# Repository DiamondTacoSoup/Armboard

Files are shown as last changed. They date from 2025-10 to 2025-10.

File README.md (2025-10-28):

# WHY ArmBoard?
We have all been there (well I have at least). Your friend says something funny, goofy, or pretty much anything and you think to yourself "I wish I could play a sound effect IRL, that would inject a lot of humour into this situation". Whether that be a generic laughing track or some obscure in joke, I believe on-demand audio add depth to any situation.

The issue we face as a society is that despite having phones which can play any sound imaginable the process of play a sound on a phone is clunky and time consuming. You must pull out and unlock your phone, look up the audio, find the correct version, wait for it to load, and then finally you can play a sound. The issue here being that this possess is time consuming, and many of these jokes/situations are time dependant.

It is clear from this that the need for a more convenient method of playing audio is required. And what could be more convenient than big buttons strapped to your wrist. It is always within arms reach, literally!  That is why I decided to create the ArmBoard, as an audio solution for the masses.

# How does it work?
The main system is comprised of 3 main parts, the esp32, the screen buttons, and the Dfplayer mini. Each of these systems have multiple sub components and functions. 

The esp32 is the brains of the operations, the TinyPico I have opted to use is optimal due to its small form factor and high number of GPIO pins. Allowing for the control of many differant components within a miniture package.

The screen buttons are made up of two distinct components, the screen and the buttons. The screens I have used are 0.66in two tone OLED displays. These are cheap, small, and bright. I have chosen to use the breakout board version of the screens as it simplifys soldering an circutry. The buttons I have chosen are the cherry MX ultra low profile. Unfortunatly these switches can only be bought from two suppliers, one in china and one in germany, they are also quite pricey. Depsite this I have still used them because of their incredibly thin form factor. 
The TinyPico does not have enough GPIO pins for each switch to have its own, as such I have arrange the switches into 4 sets of 3 switches. Each switch has a differant value resistor attatched to it (1000, 4700, and 10,000 ohm). As such, when pressed each switch in each set will produce a differant voltage. This reduces the number of Inputs needed on the TinyPico from 12 GPIO pins to just 4 analogue inputs. 
The TinyPico communicates to the Displays over I2C. Each display only supports 2 I2C addresses, as such I have had to use an I2C multiplexer to create 6 discrete I2C lines. For this task I have used the TCA9548APWR, a common I2C multiplexer. This takes one I2C line and 3 GPIO pins as input. The I2C lines carry the signal and the GPIO lines select the output using binary where each GPIO represents one digit.

Finally, the sound system consists of a DFplayer mini and a small 0.5w speaker. The DFplayer is a premade mp3 player board, the TinyPico uses a UART connection to select from mp3 files stored on an sd card within the DFplayer. The DFplayer, which incorporates a DAC, amp, and SD card, then outputs that sound signal to the speaker.

# Images
PCB:



Schematic:



3d Models:




# BOM (All prices are AUD)
| PCB designation | Name | Quantity | Product number / Website | Unit price | Total price |
|---|---|---|---|---|---|
| XA1 | TinyPico | 1 | 392-TP-N-01 | $30.40 | $30.40 |
| R10,R4,R1,R7 | 3216 Metric 1000Ohm | 4 | 704-MFBW1V3216-152-R | $0.10 | $0.38 |
| R6,R12,R15,R9,R3,R13,R16,R14 | 3216 Metric 10000Ohm | 8 | 652-CRT1206BY1002ELF | $0.21 | $1.68 |
| R8,R5,R2,R11 | 3216 Metric 4700Ohm | 4 | 603-RT1206BRD074K7L | $0.19 | $0.74 |
| U1 | TCA9548APWR | 1 | 595-TCA9548APWR | $3.65 | $3.65 |
| U2 | Dfplayer mini | 1 | [AliExpress Link](https://www.aliexpress.com/item/1005001417104130.html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!!!) | $3.06 | $3.06 |
| SW12,SW3,SW1,SW9,SW2,SW8,SW5,SW10,SW6,SW7,SW11,SW4 | Cherry ULP SMD switches | 12 | [Reichelt Link](https://www.reichelt.de/de/en/shop/product/cherry_mx_ultra_low_profile_rgb_-_pushbutton_module-335040) | $2.66 | $31.92 |
| D8,D4,D2,D12,D6,D10,D7,D3,D5,D9,D11,D1 | Display_0.66in | 12 | [BuyDisplay Link](https://www.buydisplay.com/i2c-white-0-66-inch-oled-display-module-64x48-arduino-raspberry-pi) | $4.92 | $59.04 |
| — | Battery | 1 | [AliExpress Link](https://www.aliexpress.com/p/tesla-landing/index.html?productId=4001029210544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) | $12.39 | $12.39 |
| LS1 | Buzzer_12mm (6.5mm hole) | 1 | MT-TH12-0126-RK | $2.30 | $2.30 |
| ~ | **Overall cost (excluding shipping)** | ~ | ~ | ~ | **$133.18**  |

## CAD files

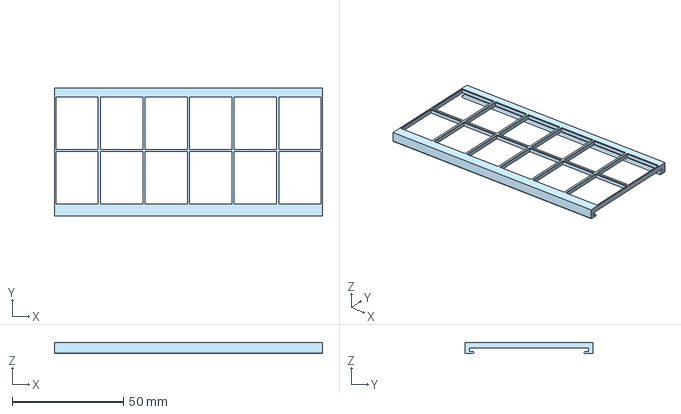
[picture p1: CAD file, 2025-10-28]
3D Models/ArmBoard Faceplate.step
120.2 x 57.4 x 5.10 mm

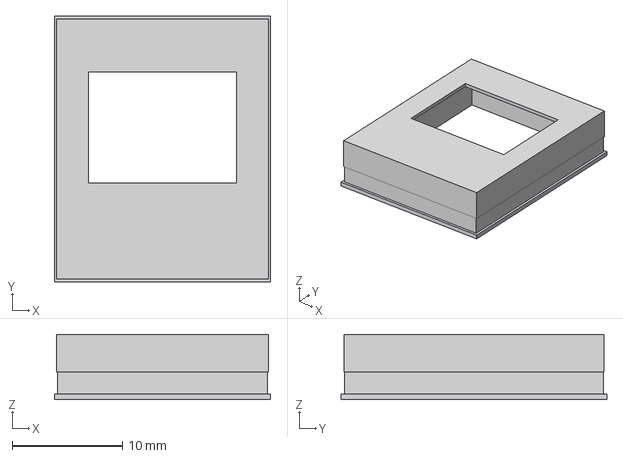
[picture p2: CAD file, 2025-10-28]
3D Models/ArmBoard Button Screen Housing.step
19.6 x 24.1 x 5.90 mm

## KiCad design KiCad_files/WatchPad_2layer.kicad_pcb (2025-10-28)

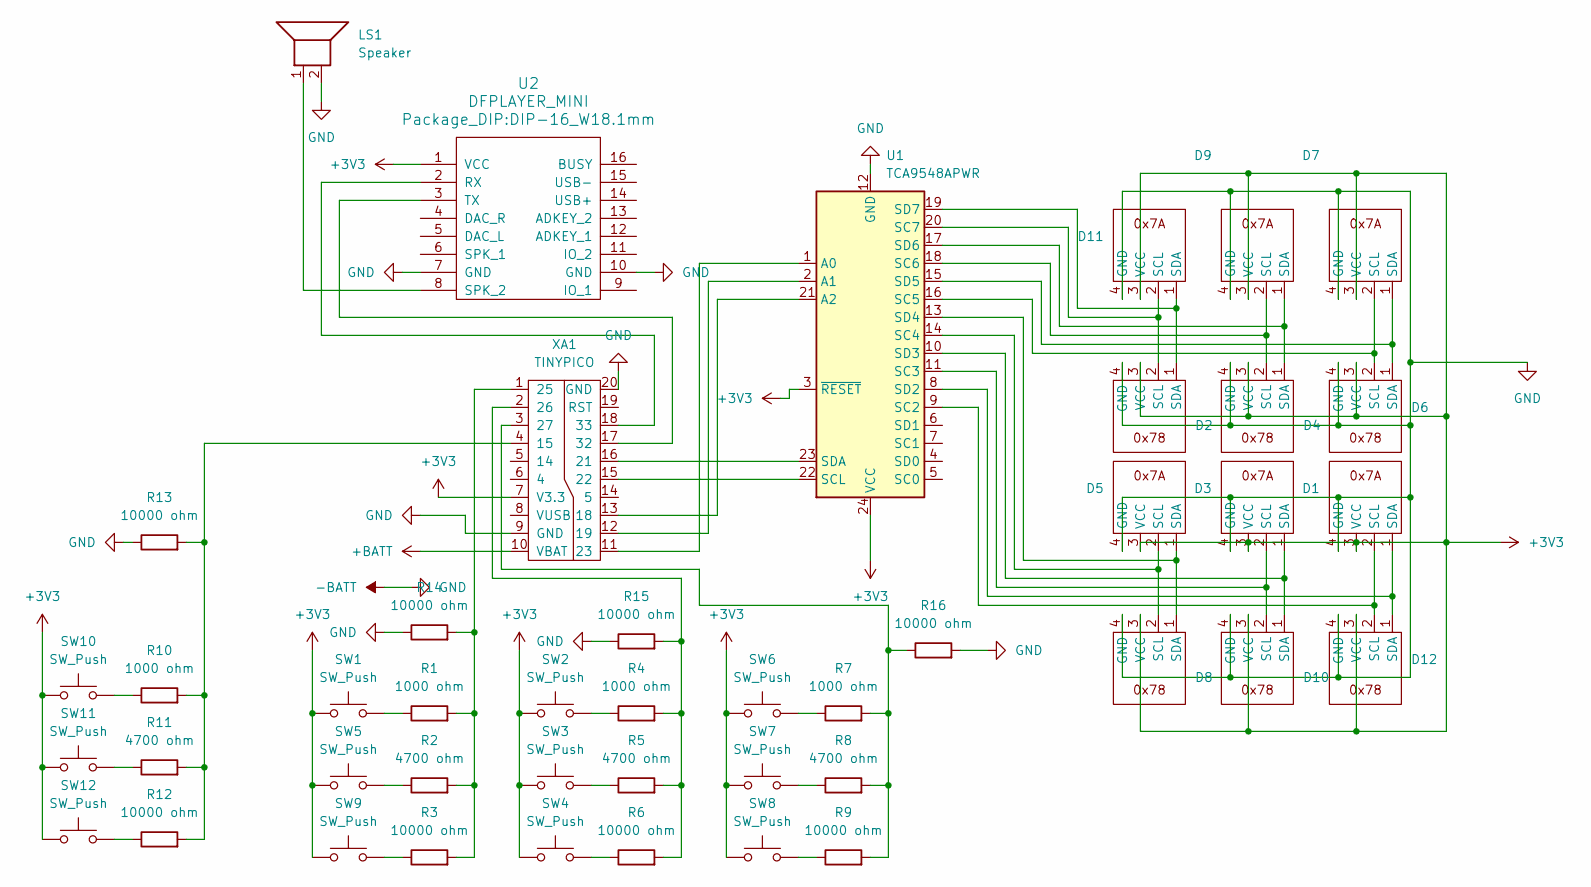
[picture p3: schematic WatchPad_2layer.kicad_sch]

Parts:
D1, D3, D5, D7, D9, D11: Display_0.66in_0x7A
D2, D4, D6, D8, D10, D12: Display_0.66in_0x78
LS1: Speaker; Buzzer_TDK_PS1240P02BT_D12.2mm_H6.5mm
R1, R4, R7, R10: 1000 ohm; R_1206_3216Metric
R2, R5, R8, R11: 4700 ohm; R_1206_3216Metric
R3, R6, R9, R12, R13, R14, R15, R16: 10000 ohm; R_1206_3216Metric
SW1, SW2, SW3, SW4, SW5, SW6, SW7, SW8, SW9, SW10, SW11, SW12: SW_Push; Cherry ULP SMD
U1: TCA9548APWR; TSSOP-24_4.4x7.8mm_P0.65mm
U2: DFPLAYER_MINI; DIP-16_W18.1mm
XA1: TINYPICO

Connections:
+3V3: D1.3 (VCC), D2.3 (VCC), D3.3 (VCC), D4.3 (VCC), D5.3 (VCC), D6.3 (VCC), D7.3 (VCC), D8.3 (VCC), D9.3 (VCC), D10.3 (VCC), D11.3 (VCC), D12.3 (VCC), SW1.1, SW2.1, SW3.1, SW4.1, SW5.1, SW6.1, SW7.1, SW8.1, SW9.1, SW10.1, SW11.1, SW12.1, U1.3 (~RESET), U1.24 (VCC), U2.1 (VCC), XA1.7 (V3.3)
+BATT: XA1.10 (VBAT)
-BATT: D1.4 (GND), D2.4 (GND), D3.4 (GND), D4.4 (GND), D5.4 (GND), D6.4 (GND), D7.4 (GND), D8.4 (GND), D9.4 (GND), D10.4 (GND), D11.4 (GND), D12.4 (GND), LS1.2, R13.1, R14.1, R15.1, R16.2, U1.12 (GND), U2.7 (GND), U2.10 (GND), XA1.9 (GND), XA1.20 (GND)
unnamed: D1.2 (SCL), D12.2 (SCL), U1.9 (SC2)
unnamed: D1.1 (SDA), D12.1 (SDA), U1.8 (SD2)
unnamed: D4.2 (SCL), D9.2 (SCL), U1.18 (SC6)
unnamed: D4.1 (SDA), D9.1 (SDA), U1.17 (SD6)
unnamed: D5.2 (SCL), D8.2 (SCL), U1.14 (SC4)
unnamed: D5.1 (SDA), D8.1 (SDA), U1.13 (SD4)
unnamed: D6.2 (SCL), D7.2 (SCL), U1.16 (SC5)
unnamed: D6.1 (SDA), D7.1 (SDA), U1.15 (SD5)
unnamed: D3.2 (SCL), D10.2 (SCL), U1.11 (SC3)
unnamed: D3.1 (SDA), D10.1 (SDA), U1.10 (SD3)
unnamed: D2.2 (SCL), D11.2 (SCL), U1.20 (SC7)
unnamed: D2.1 (SDA), D11.1 (SDA), U1.19 (SD7)
unnamed: R1.1, SW1.2
unnamed: R2.1, SW5.2
unnamed: R3.1, SW9.2
unnamed: R4.1, SW2.2
unnamed: R5.1, SW3.2
unnamed: R6.1, SW4.2
unnamed: R7.1, SW6.2
unnamed: R8.1, SW7.2
unnamed: R9.1, SW8.2
unnamed: R10.1, SW10.2
unnamed: R11.1, SW11.2
unnamed: R12.1, SW12.2
unnamed: U1.1 (A0), XA1.11 (23)
unnamed: U1.2 (A1), XA1.12 (19)
unnamed: U1.21 (A2), XA1.13 (18)
unnamed: U1.22 (SCL), XA1.15 (22)
unnamed: U1.23 (SDA), XA1.16 (21)
unnamed: U2.2 (RX), XA1.18 (33)
unnamed: LS1.1, U2.8 (SPK_2)
unnamed: U2.3 (TX), XA1.17 (32)
unnamed: R10.2, R11.2, R12.2, R13.2, XA1.4 (15)
unnamed: R1.2, R2.2, R3.2, R14.2, XA1.1 (25)
unnamed: R4.2, R5.2, R6.2, R15.2, XA1.2 (26)
unnamed: R7.2, R8.2, R9.2, R16.1, XA1.3 (27)

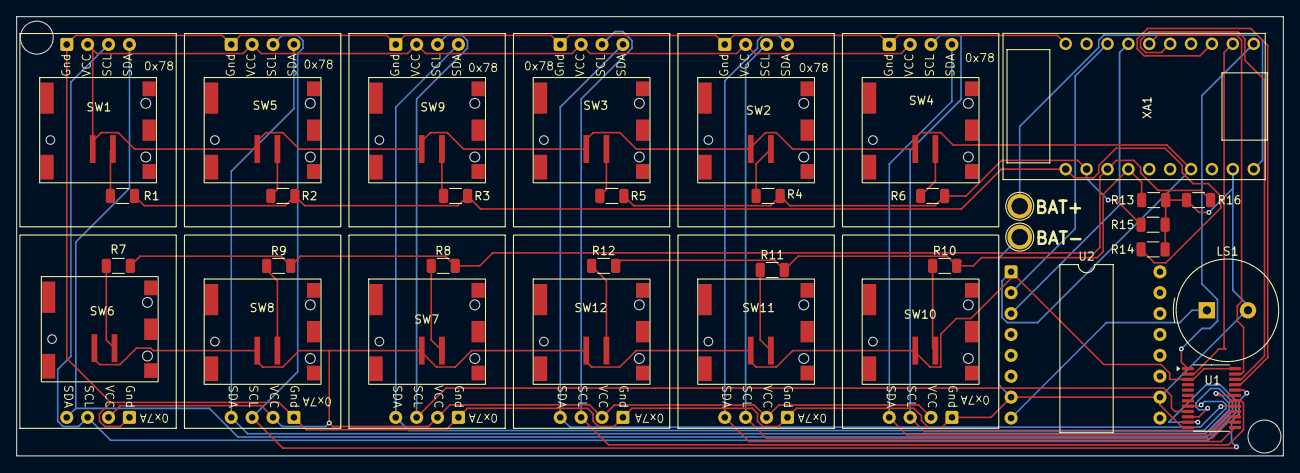
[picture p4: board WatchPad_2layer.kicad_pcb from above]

Board: 2 copper layers, 154.0 x 53.4 mm, 44 parts (0 on the bottom side), 38 nets.

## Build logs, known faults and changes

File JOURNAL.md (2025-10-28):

<!--
  ===================    !!READ THIS NOTICE!!   ====================
  DO NOT edit this file manually. Your changes WILL BE OVERWRITTEN!
  This journal is auto generated and updated by Hack Club Blueprint.
  To edit this file, please edit your journal entries on Blueprint.
  ==================================================================
-->

## 10/4/2025 - Created pcb, cad, and code.  

I didn't realise that I needed to make the journal before the designs so I went ahead and designed my project pre-journal.

PCB:
This project started out as me trying to learn Kicad, I had made some basic circuits but I wanted to try something more challenging and I have had this idea for a while so I started by making a pcb. 
My design uses a TinyPico stm32 microcontroller connected to 12 i2c displays and a dfplayer mini. 
The main challenge was that each display only supported two i2c addresses as such I have been made to use an i2c multiplexer and this was cause for much complexity in my design. Other then that the rest of the circuit is fairly straightforward. Attached are the schematics as well as the footprint:



Cad model:
The cad model at this point is quite basic, by that I mean it is completed but I will not be able to finalise the tolerances until the screens arrive and I am able to take measurements. I am also worried about the wall thickness but I have checked in preform and it should be fine for resin printing, but I may have to make modifications later.



Code:
I have gotten chatgpt to make the code. Not that I have gotten it to do everything, more that I have explained in words how I want the code to work and then have let it do the syntax (bc I hate syntax). If this is an issue I can also rewrite the code myself but that would be a pain.

## 10/28/2025 - Added BOM, Edited PCB, Edited 3D printed faceplate  

Firstly I added a BOM that Includes prices and stores, but excludes shipping costs. 
This mostly contains parts from mouser but also has a few from other suppliers.
The compilation of the BOM took quite a while.

I made some minor edits to the PCB in which I changed the hole spacing for the speaker to a more standard 6.5mm spacing.

I changed the faceplate mounting mechanism from a screw in system to a slide in system as pictured below.




## 10/29/2025 - Cleaned up ReadME, Added STEP files  

This was a minor edit to make the project ready to ship. It required uploading Images to my ReadME and Adding STEP files to my Repo. I also spent a lot of time reading through the shipping requirements to make sure I met them.



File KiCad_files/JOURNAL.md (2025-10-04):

<!--
  ===================    !!READ THIS NOTICE!!   ====================
  DO NOT edit this file manually. Your changes WILL BE OVERWRITTEN!
  This journal is auto generated and updated by Hack Club Blueprint.
  To edit this file, please edit your journal entries on Blueprint.
  ==================================================================
-->

This is my journal of the design and building process of **Armboard**.  
You can view this journal in more detail on **Hack Club Blueprint** [here](https://blueprint.hackclub.com/projects/133).

## 10/4/2025 - Created pcb, cad, and code.  

I didn't realise that I needed to make the journal before the designs so I went ahead and designed my project pre-journal.

PCB:
This project started out as me trying to learn Kicad, I had made some basic circuits but I wanted to try something more challenging and I have had this idea for a while so I started by making a pcb. 
My design uses a bluepill stm32 microcontroller connected to 12 i2c displays and a dfplayer mini. 
The main challenge was that each display only supported two i2c addresses as such I have been made to use an i2c multiplexer and this was cause for much complexity in my design. Other then that the rest of the circuit is fairly straightforward. Attached are the schematics as well as the footprint:



Cad model:
The cad model at this point is quite basic, by that I mean it is completed but I will not be able to finalise the tolerances until the screens arrive and I am able to take measurements. I am also worried about the wall thickness but I have checked in preform and it should be fine for resin printing, but I may have to make modifications later.



Code:
I have gotten chatgpt to make the code. Not that I have gotten it to do everything, more that I have explained in words how I want the code to work and then have let it do the syntax (bc I hate syntax). If this is an issue I can also rewrite the code myself but that would be a pain.

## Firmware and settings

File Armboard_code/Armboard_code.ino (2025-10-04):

#include <Wire.h>
#include <Adafruit_GFX.h>
#include <Adafruit_SSD1306.h>
#include <HardwareSerial.h>
#include <DFRobotDFPlayerMini.h>

// ---------- DISPLAY SETTINGS ----------
#define SCREEN_WIDTH 64
#define SCREEN_HEIGHT 48
#define OLED_RESET    -1
Adafruit_SSD1306 display(SCREEN_WIDTH, SCREEN_HEIGHT, &Wire, OLED_RESET);

#define TCA9548A_ADDR 0x70  // I2C address of multiplexer

// ---------- DFPLAYER SETTINGS ----------
#define DF_RX 16   // TinyPICO RX (to DFPlayer TX)
#define DF_TX 17   // TinyPICO TX (to DFPlayer RX)
HardwareSerial dfSerial(2);  
DFRobotDFPlayerMini dfPlayer;

// ---------- BUTTON SETTINGS ----------
#define COL1_PIN 34   // ADC input for column 1
#define COL2_PIN 35   // ADC input for column 2

int thresholds[6] = {400, 750, 1000, 1300, 1700, 2100}; 
// Adjust after calibration

// ---------- SYMBOL PLACEHOLDER ----------
const uint8_t symbol0[384] PROGMEM = { /* 64x48 bitmap data */ };
const uint8_t symbol1[384] PROGMEM = { /* another symbol */ };
// … up to symbol11
const uint8_t* symbols[12] = {
  symbol0, symbol1, /* … */ 
};

// ---------- HELPERS ----------
void tcaSelect(uint8_t channel) {
  if (channel > 7) return;
  Wire.beginTransmission(TCA9548A_ADDR);
  Wire.write(1 << channel);
  Wire.endTransmission();
}

int readButtonColumn(int analogPin) {
  int val = analogRead(analogPin);
  if (val < thresholds[0]) return 1;
  else if (val < thresholds[1]) return 2;
  else if (val < thresholds[2]) return 3;
  else if (val < thresholds[3]) return 4;
  else if (val < thresholds[4]) return 5;
  else if (val < thresholds[5]) return 6;
  return 0; // no button
}

// ---------- SETUP ----------
void setup() {
  Serial.begin(115200);
  Wire.begin();

  // DFPlayer
  dfSerial.begin(9600, SERIAL_8N1, DF_RX, DF_TX);
  if (!dfPlayer.begin(dfSerial)) {
    Serial.println("DFPlayer not found!");
    while(true);
  }
  dfPlayer.volume(20);

  // Test all displays
  for (int i=0; i<12; i++) {
    tcaSelect(i);
    if (!display.begin(SSD1306_SWITCHCAPVCC, 0x3C)) {
      Serial.printf("Display %d not found!\n", i);
    } else {
      display.clearDisplay();
      display.setTextSize(1);
      display.setTextColor(SSD1306_WHITE);
      display.setCursor(0,0);
      display.printf("Disp %d OK", i);
      display.display();
    }
  }
}

// ---------- LOOP ----------
void loop() {
  int button1 = readButtonColumn(COL1_PIN); // buttons 1–6
  int button2 = readButtonColumn(COL2_PIN); // buttons 7–12

  int pressed = 0;
  if (button1 > 0) pressed = button1;        // 1–6
  if (button2 > 0) pressed = button2 + 6;    // 7–12

  if (pressed > 0) {
    Serial.printf("Button %d pressed\n", pressed);

    // Show symbol
    int displayNum = pressed - 1;
    tcaSelect(displayNum);
    display.clearDisplay();
    display.drawBitmap(0, 0, symbols[displayNum], SCREEN_WIDTH, SCREEN_HEIGHT, SSD1306_WHITE);
    display.display();

    // Play sound
    dfPlayer.play(pressed); // plays 001.mp3–012.mp3
    delay(500); // debounce
  }
}

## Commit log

2025-10-04 Added Kicad files
    [WatchPad_2layer.kicad_pcb, WatchPad_2layer.kicad_sch]
2025-10-28 Added BOM and Slightly changed PCB layout
    Changed mounting solution for speaker to use more standard 6.5mm hole spacing
    [BOM_ArmBoard_AUD.csv, WatchPad_2layer.kicad_pcb, WatchPad_2layer.kicad_sch]
2025-10-28 added battery to BOM
    [BOM_ArmBoard_AUD.csv]
2025-10-28 Added STEP files
    [ArmBoard Button Screen Housing.step, ArmBoard Faceplate.step, WatchPad_2layer.kicad_pcb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]
2025-10-28 Changed BOM name to "bom.csv"
    [bom.csv]
